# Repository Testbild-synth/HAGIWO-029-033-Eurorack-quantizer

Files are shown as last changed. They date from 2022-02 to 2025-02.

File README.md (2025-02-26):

# HAGIWO 029/033 Eurorack Quantizer Module
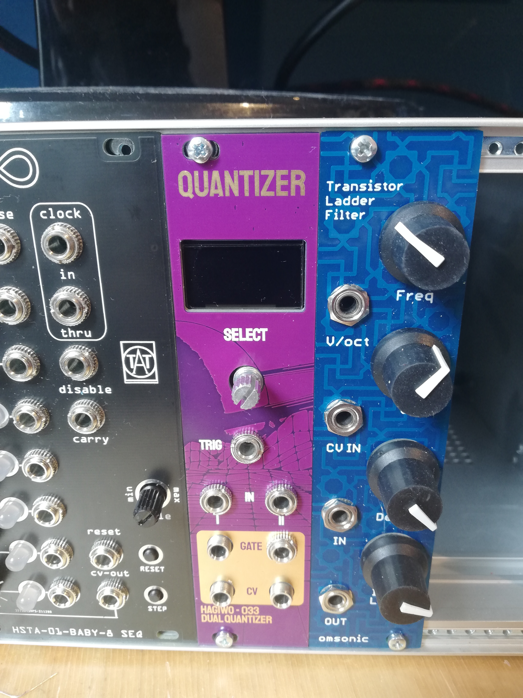
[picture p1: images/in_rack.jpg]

Through hole PCB version of the [HAGIWO 033 dual quantizer](https://www.youtube.com/watch?v=6FJpljEYZq4) and [029 SH101 sequencer](https://www.youtube.com/watch?v=--qb_QYZrTk) Eurorack Module. The modules uses a seeduino xiao and a mcp4725 dac.

The dual quantizer quantizes to notes selectable on the screen and can automatically trigger an envelope on note changes.
The SH101 sequencer allows recording and playback of cv sequences.

## Status
kind of abandoned, this is an old project and I never got around to smoothing out the kinks. Will do a new version sometimes soontm.
I cannot recommend building it at the moment.

## Hardware and PCB
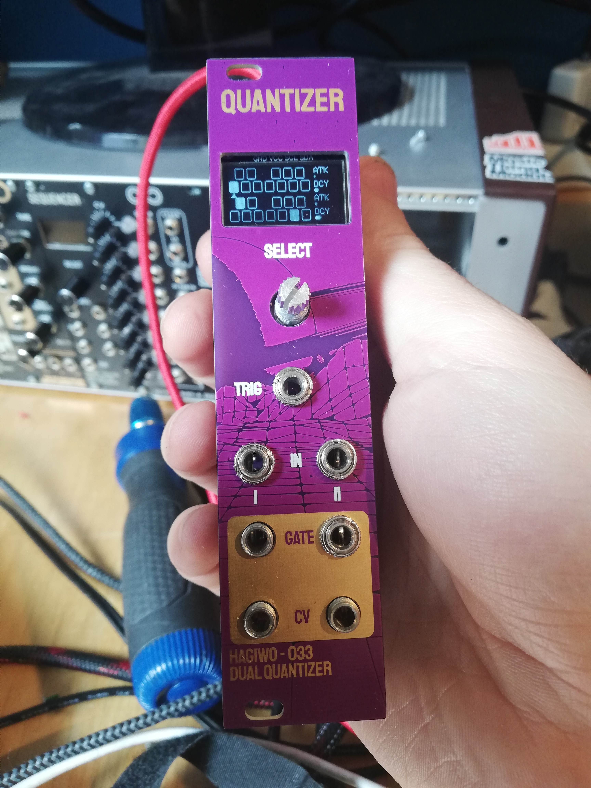
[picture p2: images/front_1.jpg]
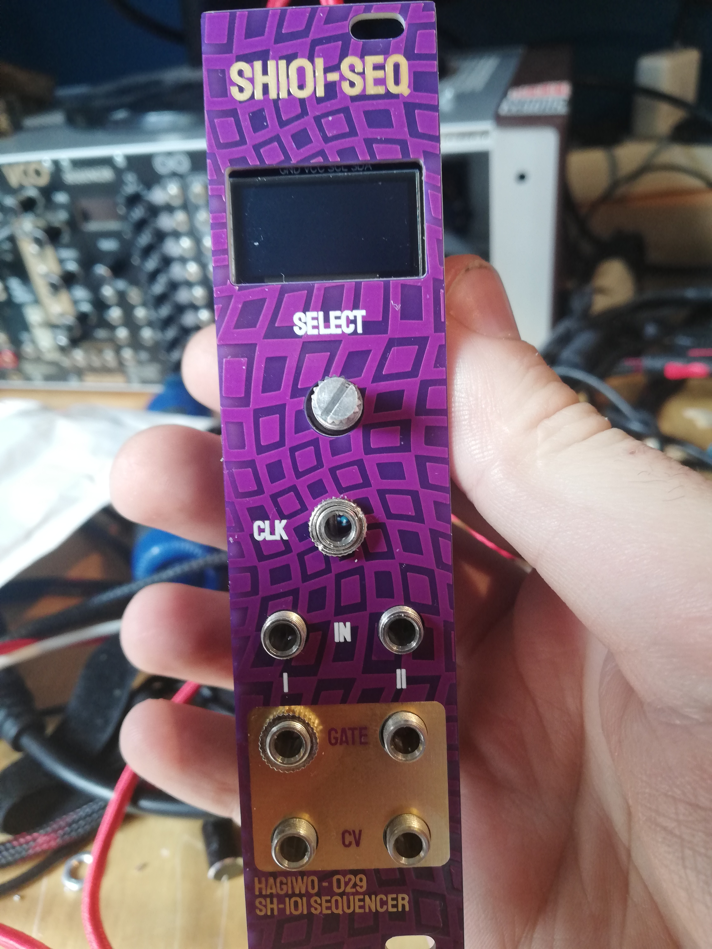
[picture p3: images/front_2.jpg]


You can find the schematic and BOM in the root folder.
For the PCBs, the module has one main circuit PCB, one control circuit PCB and one panel PCB. 
You can order them on any common PCB manufacturing service, I used [JLCPCB](https://jlcpcb.com/).
I made the circuits pcbs under 100mm to get the discount price.
Standard settings should be fine, but as there is exposed copper on the panel you should go with a lead free surface finish (ENIG/Leadfree HASL).
If the panel size is not correctly detected by JLC (happens on some of my exports) manually put 30x128.5 mm.

when ordering the display module, make sure to choose an 0.96 I2C oled module that has the pinout specified as GND-VCC-SCL-SDA as opposed to VCC-GND-SCL-SDA (both exist and the latter will fuck it up).    

Also make sure you order a Seediuno XIAO (with a SAMD21/Cortex M0 chip) as opposed to the XIAO esp32c3 or the XIAO rp2040, those are different chips.

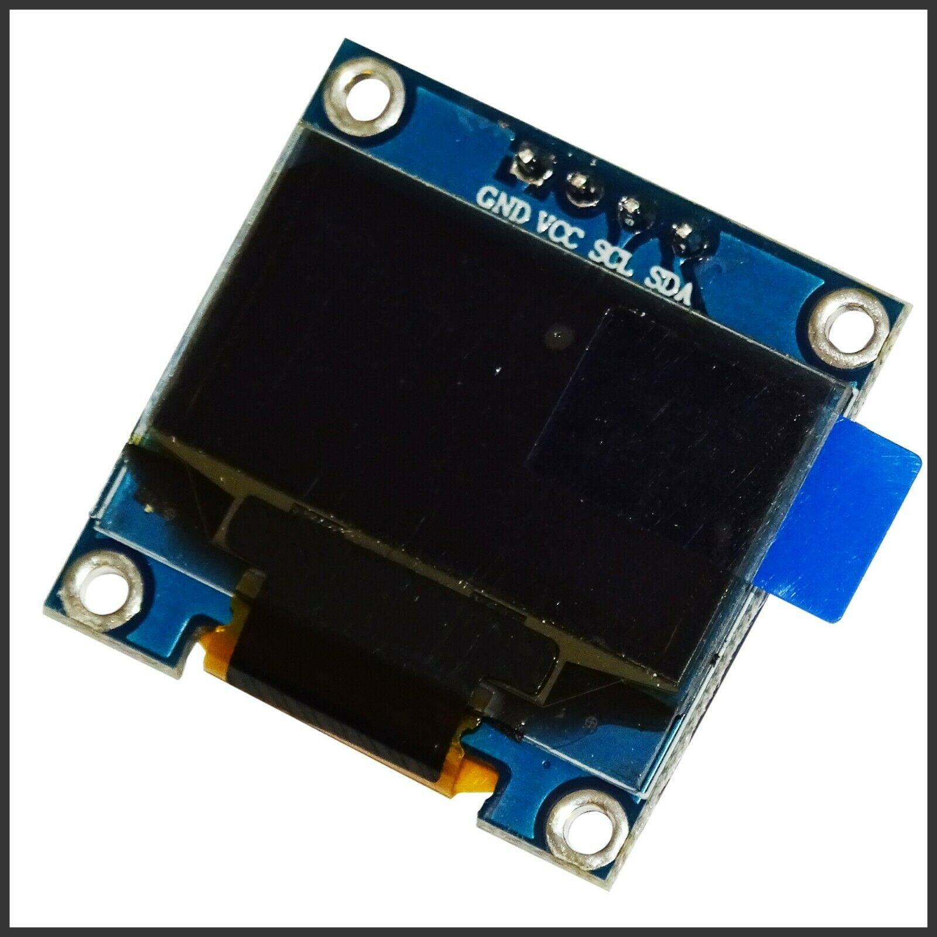
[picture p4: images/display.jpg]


## Assembly

When assembling, you can either use a header for the screen or solder it directly, as it is a litte too tall.
The 7805 voltage regulator is optional, if you do not want to use it, simply solder the SEL header on the back of the main pcb to BOARD instead of REG (meaning you bridge the connection to choose your 5v voltage source to either be 12 regulated to 5v, or a 5V connection of your rack power if you have it).

## Tuning
There are two things  in the circuit that need to be tuned for: The input resistor divider going from 5V to 3.3V, and the output opamp gain to go from 3.3 back to 5V.
I will provide a script to help with this and a detailed description in the future, but for now the short version is: Input resistors are compensated for in code with the ADC_calb parameters. Output gain is adjusted using the trimmers on the main pcb.

## Arduino Code

### Double Quantizer
HAGIWO did great work, but I decided to make some changes to the Arduino code because I had ADC issues on my seeduino Xiao.

The main changes are:
 - HAGIWO had a check that cv is only updated then there's a big enough change from the last value. I took this out since I want to be able to process slow cv changes (i.e. from LFOs), also. 
 - I followed suggestions from [this very nice blog about adc accuracy on samd21](https://blog.thea.codes/getting-the-most-out-of-the-samd21-adc/). With lower input impedance and the changes from this blog, the readings got a lot more accurate on mine. Downside is more latency (in the single ms range) but frankly im willing to take that for more stability/less noise.
 - Also, to make use of this, the note calculation is now done with 12 bit instead of downsampling the adc values to 10 bit.
 - Comment out the specified lines in the code if you dont want the slower adc.

## TODO:
- Test and verify SH101 firmware
- maybe add display indication for played notes

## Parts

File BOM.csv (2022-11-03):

Name | Designator | Footprint | Quantity
18k | R14,R19 | R_AXIAL-0.3 | 2
Header-Male-2.54_1x8 | R9,R3 | TRIMPOT-ELETROCURSOS-FOOTPRINT | 2
33k | R15,R21,R18 | R_AXIAL-0.3 | 3
3k3 | R16,R17 | R_AXIAL-0.3 | 2
1k | R6,R12 | R_AXIAL-0.3 | 2
10k | R7,R1 | R_AXIAL-0.3 | 2
6.8k | R8,R2 | R_AXIAL-0.3 | 2
330 | R10,R11,R4,R5 | R_AXIAL-0.3 | 4
10n ceramic | C7,C8,C9,C10 | RAD-0.1 | 4
470n ceramic | C1,C4 | RAD-0.1 | 2
100n ceramic | C2,C5,C6 | RAD-0.1 | 3
10u electrolytic | C3 | CAP-D4.0×F1.5 | 1
BAT43 | D1,D2,D3,D4,D5,D6 | D_DO-35_SOD27_P7.62MM_HORIZONTAL | 6
Header-Male-2.54_1x8 | H1,H2 | HDR-TH_8P-P2.54-V-M | 2
470 | R13,R20 | R_AXIAL-0.3 | 2
ALPS_ENCODER+PUSHSWITCH | ENC |  | 1
THONKICONN JACK | J1-J7 |  | 7
BC547A | Q1,Q2 | TO92-INLINE | 2
MCP6002-EP | U1 | DIP8 | 1
MCP4725 Breakout | CN1 | MCP4725-B | 1
POWER HEADER | P1 | HDR-IDC-2.54-2X8P | 1
Seeeduino XIAO (SAMD21) | SEEDUINO | SEEDUINO XIAO | 1
7805 Voltage regulator | U3 | 7805 | 1

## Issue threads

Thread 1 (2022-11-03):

Can't compile Arduino Quantizer code due to various errors

guytanium, 2022-11-03:
Hey! I just finished building this module.
I am not sure how to resolve the issues trying to flash my Xiao RP2040. First I was having issues with Encoder interrupts (which I turned off) and now can't seem to pick up anything associated with ADC or PWM.

First I updated all libraries then I installed [arduino-pico](https://github.com/earlephilhower/arduino-pico) into Boards Manager. "Seeed XIAO RP2040" selected in Raspberry Pi RP2040 Boards(2.6.2) under the Boards menu.

Then I manually updated [Encoder](https://github.com/PaulStoffregen/Encoder) to 1.4.3, only 1.4.2 shows in Arduino Library Manager.
I was getting errors that interrupts are not supported such as:
`/Users/guy/Documents/Arduino/libraries/Encoder/utility/interrupt_pins.h:390:2: error: #error "Interrupts are unknown for this board, please add to this code"
  390 | #error "Interrupts are unknown for this board, please add to this code"
      |  ^~~~~
/Users/guy/Documents/Arduino/libraries/Encoder/utility/interrupt_pins.h:393:2: error: #error "Encoder requires interrupt pins, but this board does not have any :("
  393 | #error "Encoder requires interrupt pins, but this board does not have any :("
      |  ^~~~~
/Users/guy/Documents/Arduino/libraries/Encoder/utility/interrupt_pins.h:394:2: error: #error "You could try defining ENCODER_DO_NOT_USE_INTERRUPTS as a kludge."
  394 | #error "You could try defining ENCODER_DO_NOT_USE_INTERRUPTS as a kludge."`

So I switched `#define  ENCODER_OPTIMIZE_INTERRUPTS` to `ENCODER_DO_NOT_USE_INTERRUPTS` to get past this error.

Next set of errors
`WARNING: library FlashStorage claims to run on samd architecture(s) and may be incompatible with your current board which runs on rp2040 architecture(s).
In file included from /Users/guy/Downloads/double_quantizer/double_quantizer.ino:13:
/Users/guy/Documents/Arduino/libraries/Encoder/Encoder.h:68:11: error: 'IO_REG_TYPE' does not name a type; did you mean 'IP_GET_TYPE'?
   68 |  volatile IO_REG_TYPE * pin1_register;
      |           ^~~~~~~~~~~
      |           IP_GET_TYPE
/Users/guy/Documents/Arduino/libraries/Encoder/Encoder.h:69:11: error: 'IO_REG_TYPE' does not name a type; did you mean 'IP_GET_TYPE'?
   69 |  volatile IO_REG_TYPE * pin2_register;
      |           ^~~~~~~~~~~
      |           IP_GET_TYPE
/Users/guy/Documents/Arduino/libraries/Encoder/Encoder.h:70:2: error: 'IO_REG_TYPE' does not name a type; did you mean 'IP_GET_TYPE'?
   70 |  IO_REG_TYPE            pin1_bitmask;
      |  ^~~~~~~~~~~
      |  IP_GET_TYPE
/Users/guy/Documents/Arduino/libraries/Encoder/Encoder.h:71:2: error: 'IO_REG_TYPE' does not name a type; did you mean 'IP_GET_TYPE'?
   71 |  IO_REG_TYPE            pin2_bitmask;
      |  ^~~~~~~~~~~
      |  IP_GET_TYPE
/Users/guy/Documents/Arduino/libraries/Encoder/Encoder.h: In constructor 'Encoder::Encoder(uint8_t, uint8_t)':
/Users/guy/Documents/Arduino/libraries/Encoder/Encoder.h:89:11: error: 'struct Encoder_internal_state_t' has no member named 'pin1_register'
   89 |   encoder.pin1_register = PIN_TO_BASEREG(pin1);
      |           ^~~~~~~~~~~~~
/Users/guy/Documents/Arduino/libraries/Encoder/Encoder.h:89:27: error: 'PIN_TO_BASEREG' was not declared in this scope
   89 |   encoder.pin1_register = PIN_TO_BASEREG(pin1);
      |                           ^~~~~~~~~~~~~~
/Users/guy/Documents/Arduino/libraries/Encoder/Encoder.h:90:11: error: 'struct Encoder_internal_state_t' has no member named 'pin1_bitmask'
   90 |   encoder.pin1_bitmask = PIN_TO_BITMASK(pin1);
      |           ^~~~~~~~~~~~
/Users/guy/Documents/Arduino/libraries/Encoder/Encoder.h:90:26: error: 'PIN_TO_BITMASK' was not declared in this scope
   90 |   encoder.pin1_bitmask = PIN_TO_BITMASK(pin1);
      |                          ^~~~~~~~~~~~~~
/Users/guy/Documents/Arduino/libraries/Encoder/Encoder.h:91:11: error: 'struct Encoder_internal_state_t' has no member named 'pin2_register'
   91 |   encoder.pin2_register = PIN_TO_BASEREG(pin2);
      |           ^~~~~~~~~~~~~
/Users/guy/Documents/Arduino/libraries/Encoder/Encoder.h:92:11: error: 'struct Encoder_internal_state_t' has no member named 'pin2_bitmask'
   92 |   encoder.pin2_bitmask = PIN_TO_BITMASK(pin2);
      |           ^~~~~~~~~~~~
/Users/guy/Documents/Arduino/libraries/Encoder/Encoder.h:99:31: error: 'struct Encoder_internal_state_t' has no member named 'pin1_register'
   99 |   if (DIRECT_PIN_READ(encoder.pin1_register, encoder.pin1_bitmask)) s |= 1;
      |                               ^~~~~~~~~~~~~
/Users/guy/Documents/Arduino/libraries/Encoder/Encoder.h:99:54: error: 'struct Encoder_internal_state_t' has no member named 'pin1_bitmask'
   99 |   if (DIRECT_PIN_READ(encoder.pin1_register, encoder.pin1_bitmask)) s |= 1;
      |                                                      ^~~~~~~~~~~~
/Users/guy/Documents/Arduino/libraries/Encoder/Encoder.h:99:7: error: 'DIRECT_PIN_READ' was not declared in this scope
   99 |   if (DIRECT_PIN_READ(encoder.pin1_register, encoder.pin1_bitmask)) s |= 1;
      |       ^~~~~~~~~~~~~~~
/Users/guy/Documents/Arduino/libraries/Encoder/Encoder.h:100:31: error: 'struct Encoder_internal_state_t' has no member named 'pin2_register'
  100 |   if (DIRECT_PIN_READ(encoder.pin2_register, encoder.pin2_bitmask)) s |= 2;
      |                               ^~~~~~~~~~~~~
/Users/guy/Documents/Arduino/libraries/Encoder/Encoder.h:100:54: error: 'struct Encoder_internal_state_t' has no member named 'pin2_bitmask'
  100 |   if (DIRECT_PIN_READ(encoder.pin2_register, encoder.pin2_bitmask)) s |= 2;
      |                                                      ^~~~~~~~~~~~
/Users/guy/Documents/Arduino/libraries/Encoder/Encoder.h:100:7: error: 'DIRECT_PIN_READ' was not declared in this scope
  100 |   if (DIRECT_PIN_READ(encoder.pin2_register, encoder.pin2_bitmask)) s |= 2;
      |       ^~~~~~~~~~~~~~~
/Users/guy/Documents/Arduino/libraries/Encoder/Encoder.h: In static member function 'static void Encoder::update(Encoder_internal_state_t*)':
/Users/guy/Documents/Arduino/libraries/Encoder/Encoder.h:303:40: error: 'struct Encoder_internal_state_t' has no member named 'pin1_register'
  303 |   uint8_t p1val = DIRECT_PIN_READ(arg->pin1_register, arg->pin1_bitmask);
      |                                        ^~~~~~~~~~~~~
/Users/guy/Documents/Arduino/libraries/Encoder/Encoder.h:303:60: error: 'struct Encoder_internal_state_t' has no member named 'pin1_bitmask'
  303 |   uint8_t p1val = DIRECT_PIN_READ(arg->pin1_register, arg->pin1_bitmask);
      |                                                            ^~~~~~~~~~~~
/Users/guy/Documents/Arduino/libraries/Encoder/Encoder.h:303:19: error: 'DIRECT_PIN_READ' was not declared in this scope
  303 |   uint8_t p1val = DIRECT_PIN_READ(arg->pin1_register, arg->pin1_bitmask);
      |                   ^~~~~~~~~~~~~~~
/Users/guy/Documents/Arduino/libraries/Encoder/Encoder.h:304:40: error: 'struct Encoder_internal_state_t' has no member named 'pin2_register'
  304 |   uint8_t p2val = DIRECT_PIN_READ(arg->pin2_register, arg->pin2_bitmask);
      |                                        ^~~~~~~~~~~~~
/Users/guy/Documents/Arduino/libraries/Encoder/Encoder.h:304:60: error: 'struct Encoder_internal_state_t' has no member named 'pin2_bitmask'
  304 |   uint8_t p2val = DIRECT_PIN_READ(arg->pin2_register, arg->pin2_bitmask);
      |                                                            ^~~~~~~~~~~~
/Users/guy/Downloads/double_quantizer/double_quantizer.ino: In function 'void setup()':
double_quantizer:94:2: error: 'REG_ADC_AVGCTRL' was not declared in this scope
   94 |  REG_ADC_AVGCTRL |= ADC_AVGCTRL_SAMPLENUM_1;
      |  ^~~~~~~~~~~~~~~
double_quantizer:94:21: error: 'ADC_AVGCTRL_SAMPLENUM_1' was not declared in this scope
   94 |  REG_ADC_AVGCTRL |= ADC_AVGCTRL_SAMPLENUM_1;
      |                     ^~~~~~~~~~~~~~~~~~~~~~~
double_quantizer:95:2: error: 'ADC' was not declared in this scope
   95 |  ADC->AVGCTRL.reg = ADC_AVGCTRL_SAMPLENUM_128 | ADC_AVGCTRL_ADJRES(4);
      |  ^~~
double_quantizer:95:21: error: 'ADC_AVGCTRL_SAMPLENUM_128' was not declared in this scope
   95 |  ADC->AVGCTRL.reg = ADC_AVGCTRL_SAMPLENUM_128 | ADC_AVGCTRL_ADJRES(4);
      |                     ^~~~~~~~~~~~~~~~~~~~~~~~~
double_quantizer:95:49: error: 'ADC_AVGCTRL_ADJRES' was not declared in this scope
   95 |  ADC->AVGCTRL.reg = ADC_AVGCTRL_SAMPLENUM_128 | ADC_AVGCTRL_ADJRES(4);
      |                                                 ^~~~~~~~~~~~~~~~~~
/Users/guy/Downloads/double_quantizer/double_quantizer.ino: In function 'void PWM1(int)':
double_quantizer:722:2: error: 'pwm' was not declared in this scope
  722 |  pwm(ENV_OUT_PIN_1, 46000, duty1);
      |  ^~~
/Users/guy/Downloads/double_quantizer/double_quantizer.ino: In function 'void PWM2(int)':
double_quantizer:725:2: error: 'pwm' was not declared in this scope
  725 |  pwm(ENV_OUT_PIN_2, 46000,  duty2);
      |  ^~~
exit status 1
'REG_ADC_AVGCTRL' was not declared in this scope`

Are you using a different set up in board manager? It looks like Arduino IDE doesn't know anything about the pinouts or environment for RP2040. Thanks

Testbild-synth, 2022-11-03:
hi @guytanium , the problem is probably that you are using an RP2040 instead of a regular Xiao, which has a Samd21/cortex m0 chip. Seed studios has kind of confusing naming conventions for the uC boards, but they are two entirely different products. (there is also a xiao esp32 which is yet another different thing altogether)

Hagiwo made the code for the Xiao with the samd21 chip and you will probably have to manually change a bunch of things related to the dac/adc settings if you want to run it on an RP2040 (not even sure if the pins match). I will update the BOM to reflect this more closely in the future

Testbild-synth, 2022-11-03:
if you want to try using the 2040, you can try the following steps:
1. Make sure that the pins actually match (as in that analog/digital io and voltage supply pins for both boards are the same)
2. comment out line 93 and 94 (those are the samd21 related adc settings) and try to compile again
3. Check if adc resolution on the rp2040 is also 12 bit and if you can get the pwm to behave the same way (might be tricky).

But again this is not officially supported, if you get a version working with the 2040 feel free to create a pullrequest and we can add this as a separate firmware

guytanium, 2022-11-03:
Oh wow. That’s embarrassing I bought the wrong microcontroller!  Thanks for the fast reply. I’m sure I can find another use for my 2040, now to source a samd21 chip.

Closed 2022-11-03.

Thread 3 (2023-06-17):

about tuning process

b2unit69, 2023-06-17:
I am currently working on a module, following your project exactly. I do not have any electronic knowledge, so I do not understand the tuning that you explained very well. If you are okay with it, could you please explain the tuning process in detail? Thank you.

Testbild-synth, 2023-07-04:
honestly this was my second ever project and I never really followed through on the explanation. I will try to redo the whole thing soon and make it more usable but for your build ill try to find a solution. I'll get back to you next week

b2unit69, 2023-07-06:
thank you for the answer :)
I did tunning process on my own. Is this correct?

5v to 3.3v (scale down)
Vin(5v) *(R21(33k)/R21(33k)+R19(18k) = Vout(A)
5v:1 - Av:a(AD_CH1_calb) (in my case AD_CH1_calb = 0.971)

3.3v to 5v(scale up)
5v/3.3v = 1.51515
0.51515 = 5k(adjustable)/6.5k
set the 5k trim pot value( in my case around 3.5k)

when cv in volatage around 4.5v to 5v
When a cv in value reaches around 4.5v to 5v, it becomes the same high value. Is this normal?

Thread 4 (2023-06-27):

HAGIWO-029-033-Eurorack-Quantisierer

Terry-Trasher, 2023-06-27:
Hallo,

wie geht es dir?
Ich habe ein Problem Arduino. Ich will die Firmware flashen, aber kommt immer ein Problem mit pwm.

Ich hatte die Firmware von dir genommen.

void PWM1(int duty1) {
  pwm(ENV_OUT_PIN_1, 46000, duty1);
}
void PWM2(int duty2) {
 pwm(ENV_OUT_PIN_2, 46000, duty2);
}

**double_quantizer:721:3: error: 'pwm' was not declared in this scope
   pwm(ENV_OUT_PIN_1, 46000, duty1);
   ^~~**

**double_quantizer:724:2: error: 'pwm' was not declared in this scope
  pwm(ENV_OUT_PIN_2, 46000, duty2);
  ^~~
exit status 1
'pwm' was not declared in this scope**

Wo ist das Problem? Ich hatte in verschiedene Forum belesen, aber bin nicht schlau geworden.

Ich bedanke mich Vorab.

Grüß

Terry

Closed 2023-06-28.

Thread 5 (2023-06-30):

mcp6002 Vss, Vdd wiring in pcb

b2unit69, 2023-06-30:
please check mcp6002 pin4(Vss), pin8(Vdd) connection.
pin4(Vss) is connected 5v and pin8(Vdd) is connected GND in PCB. is this right? let me know..

b2unit69, 2023-07-03:
situation: using 5v from case power supply without 7805
now I can hear sound but don't know well about tunning.

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

Testbild-synth, 2023-07-04:
you are correct. This was an issue with the first batch of pcbs which I thought I fixed years ago but turns out I never really uploaded the files (shame on me).
Sorry you had to go through the build process with a broken pcb and thanks for reminding, I uploaded new files that should reflect the new orientation.

Closed 2023-07-06.

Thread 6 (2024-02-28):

Marking error on control pannel & CV out bug

lookitsgraphic, 2024-02-28:
The marking of 4 resistors on the control panel are wrong, the 2X 18k and 33k resistor are marked as 220k and 330k resistor on the pcb.
So I still have a problem, when I plug in the module, it seems to recognize the CV signals (because it is trig) but the quantizer does not seem to work (the CV signal sent is always the same).

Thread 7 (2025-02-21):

fatal error: FlashAsEEPROM.h: No such file or directory

K-Teck-Dave, 2025-02-21:
i'm a complete arduino novice
what libraries do i need to include?
i installed FlashStorage_SAMD
and AceWire - because Wire.h is missing too...

i'm not sure what to do next

K-Teck-Dave, 2025-02-22:
ok... i have it all working on the screen... but no quantising going on... i'll investigate further

K-Teck-Dave, 2025-02-22:
all sorted... super module... thanks

K-Teck-Dave, 2025-02-22:
closing

Closed 2025-02-22.

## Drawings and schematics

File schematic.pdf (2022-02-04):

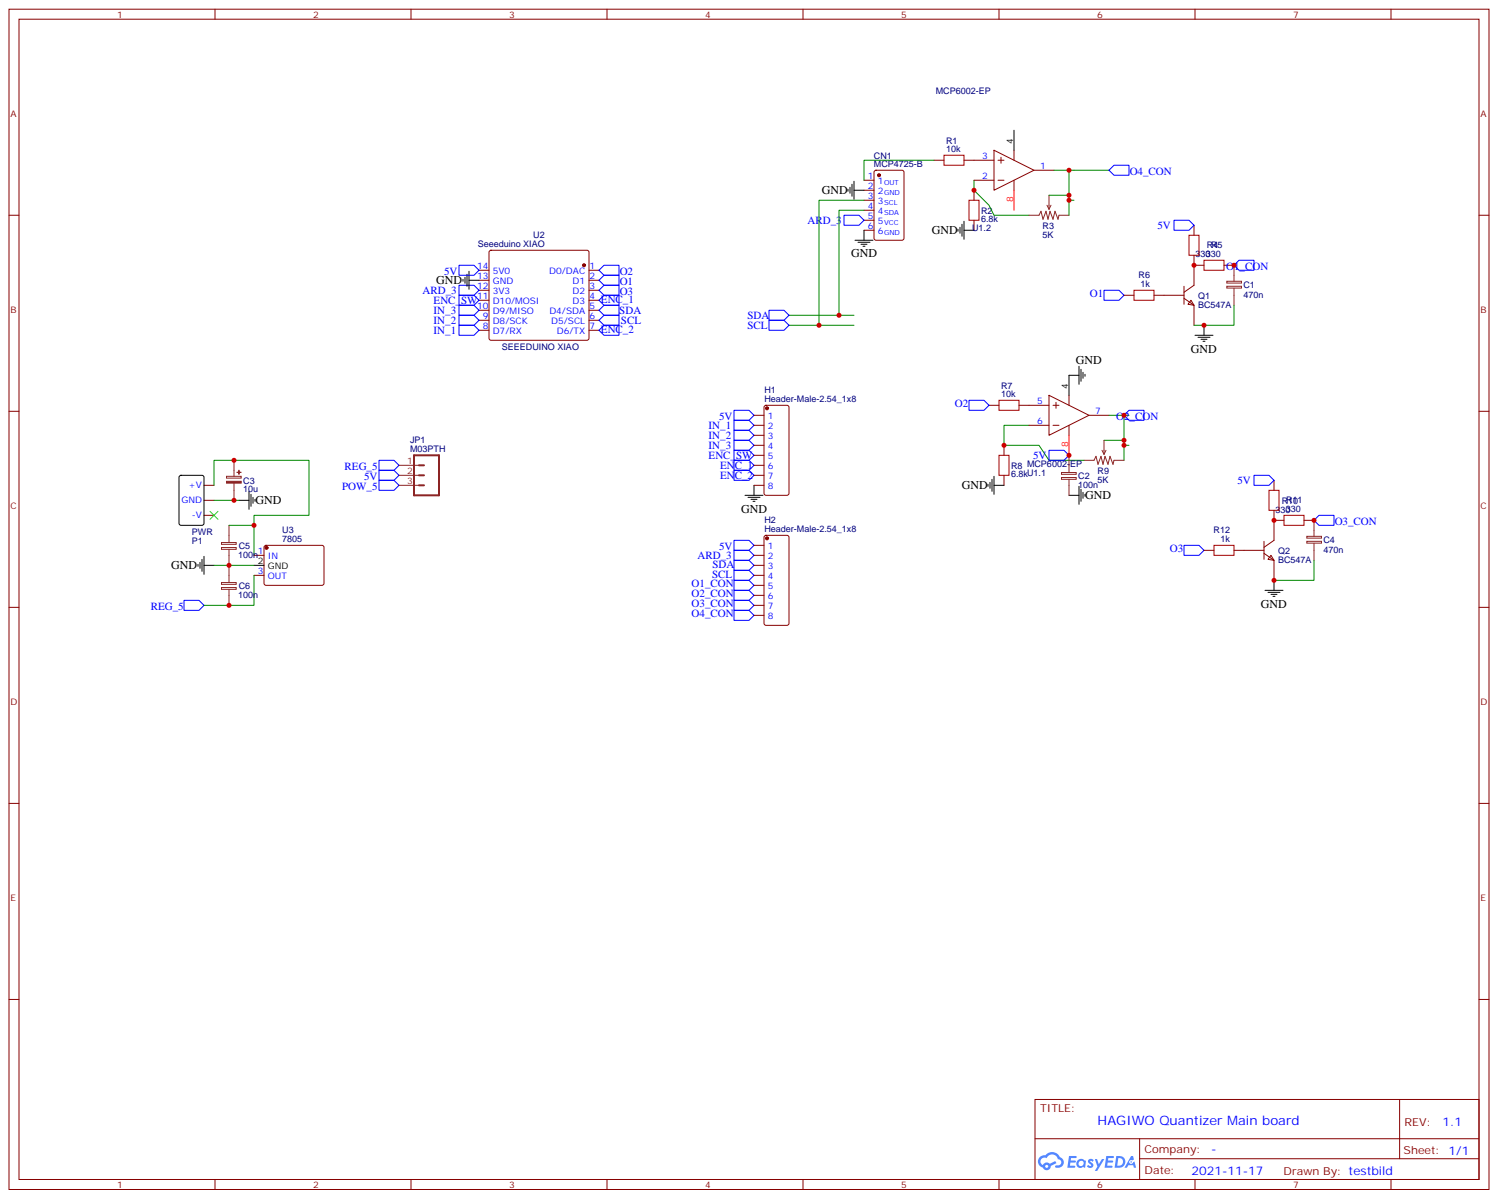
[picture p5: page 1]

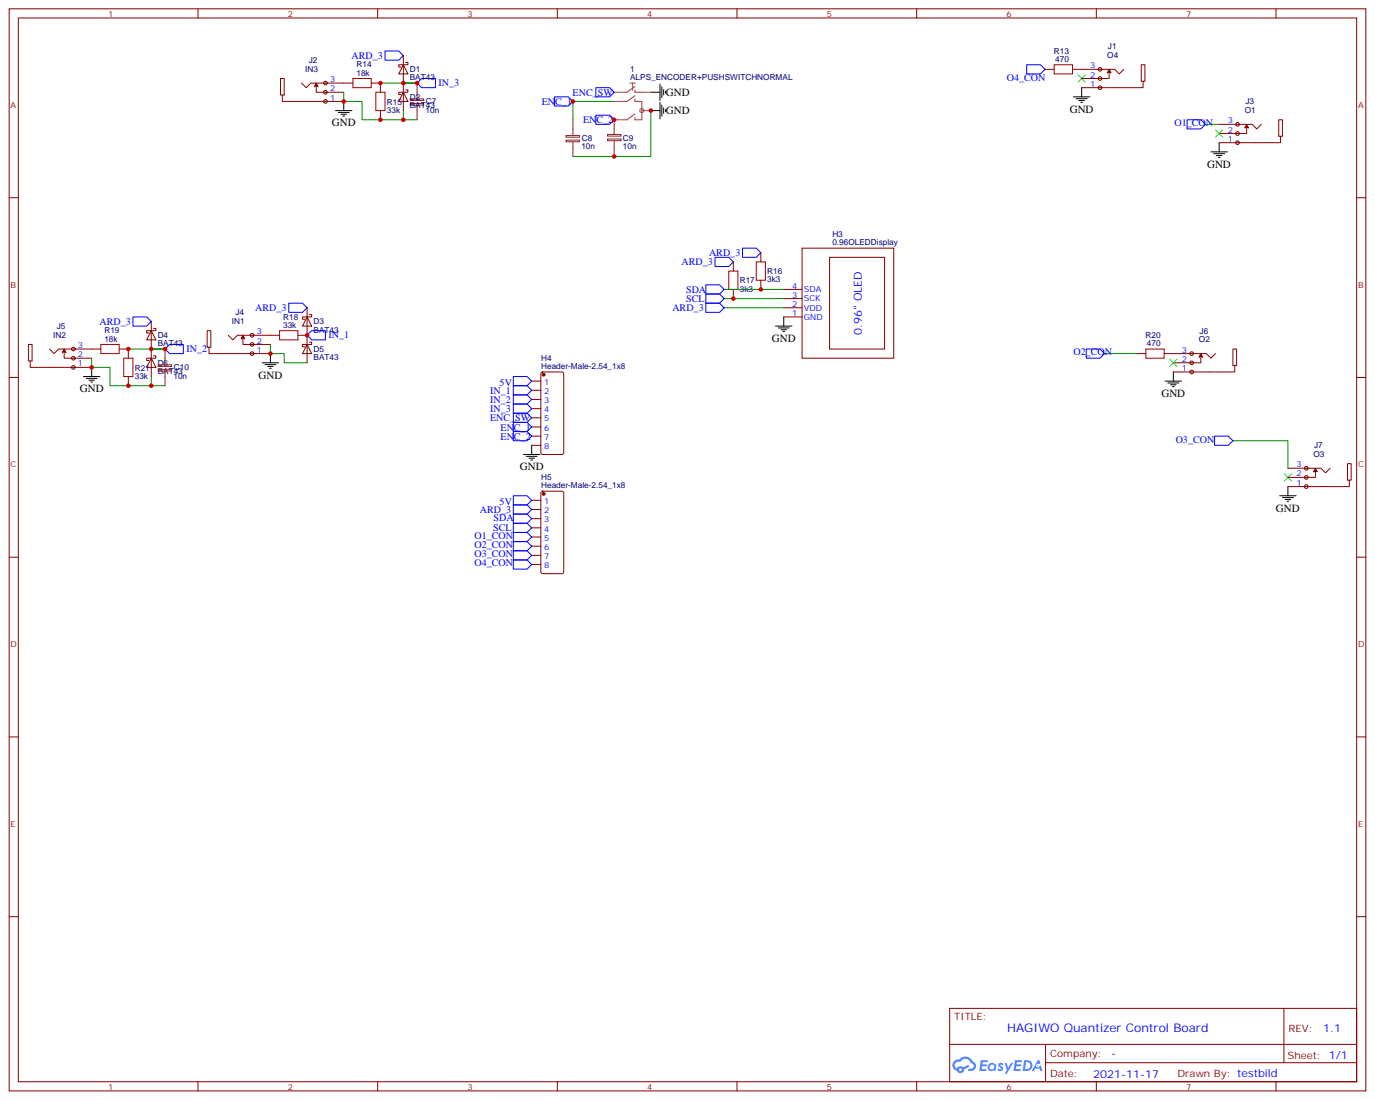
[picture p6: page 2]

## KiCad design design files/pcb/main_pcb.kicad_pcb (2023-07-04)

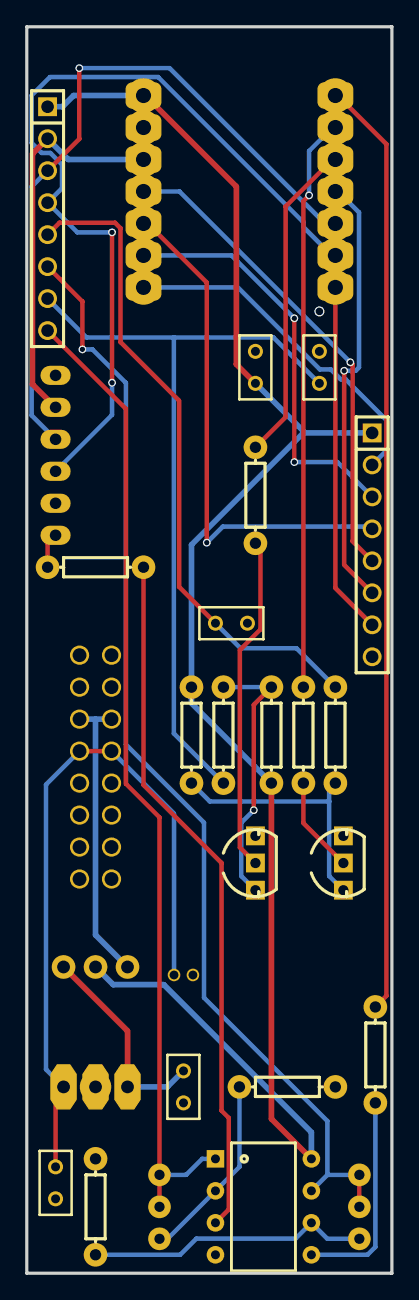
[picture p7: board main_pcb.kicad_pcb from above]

Board: 2 copper layers, 29.0 x 99.0 mm, 28 parts (0 on the bottom side), 30 nets.

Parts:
C1, C4: 470n; RAD-0.1
C2, C5, C6: 100n; RAD-0.1
C3: 10u; CAP-D4.0×F1.5
CN1: MCP4725-B
H4, H5: Header-Male-2.54_1x8; HDR-TH_8P-P2.54-V-M
P1: PWR; HDR-IDC-2.54-2X8P
Q1, Q2: BC547A; TO92-INLINE
R1, R7: 10k; R_AXIAL-0.3
R2, R8: 6.8k; R_AXIAL-0.3
R3, R9: 5K; TRIMPOT-ELETROCURSOS-FOOTPRINT
R4, R5, R10, R11: 330; R_AXIAL-0.3
R6, R12: 1k; R_AXIAL-0.3
SEEDUINO: Seeeduino XIAO; SEEDUINO XIAO
SEL: M03PTH; 1X03
U1: MCP6002-EP; DIP8
U3: 7805

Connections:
5V: C2.2, H4.1, H5.1, R4.2, R10.2, SEEDUINO.14, SEL.2, U1.8
ARD_3: CN1.5, H5.2, SEEDUINO.12
CN1_1: CN1.1, R1.1
ENC_1: H4.6, SEEDUINO.4
ENC_2: H4.7, SEEDUINO.7
ENC_SW: H4.5, SEEDUINO.11
GND: C1.2, C2.1, C3.2, C4.2, C5.1, C6.2, CN1.2, CN1.6, H4.8, P1.3, P1.4, P1.5, P1.6, P1.7, P1.8, Q1.3, Q2.3, R2.1, R8.1, SEEDUINO.13, U1.4, U3.2
IN_1: H4.2, SEEDUINO.8
IN_2: H4.3, SEEDUINO.9
IN_3: H4.4, SEEDUINO.10
O1: R6.1, SEEDUINO.2
O1_CON: C1.1, H5.5, R5.1
O2: R7.1, SEEDUINO.1
O2_CON: H5.6, R9.2, R9.3, U1.7
O3: R12.1, SEEDUINO.3
O3_CON: C4.1, H5.7, R11.1
O4_CON: H5.8, R3.2, R3.3, U1.1
P1_10: C3.1, C5.2, P1.9, P1.10, U3.1
POW_5: P1.11, P1.12, SEL.3
Q1_1: Q1.1, R4.1, R5.2
Q2_1: Q2.1, R10.1, R11.2
R1_2: R1.2, U1.3
R2_2: R2.2, R3.1, U1.2
R6_2: Q1.2, R6.2
R7_2: R7.2, U1.5
R9_1: R8.2, R9.1, U1.6
R12_2: Q2.2, R12.2
REG_5: C6.1, SEL.1, U3.3
SCL: CN1.3, H5.4, SEEDUINO.6
SDA: CN1.4, H5.3, SEEDUINO.5

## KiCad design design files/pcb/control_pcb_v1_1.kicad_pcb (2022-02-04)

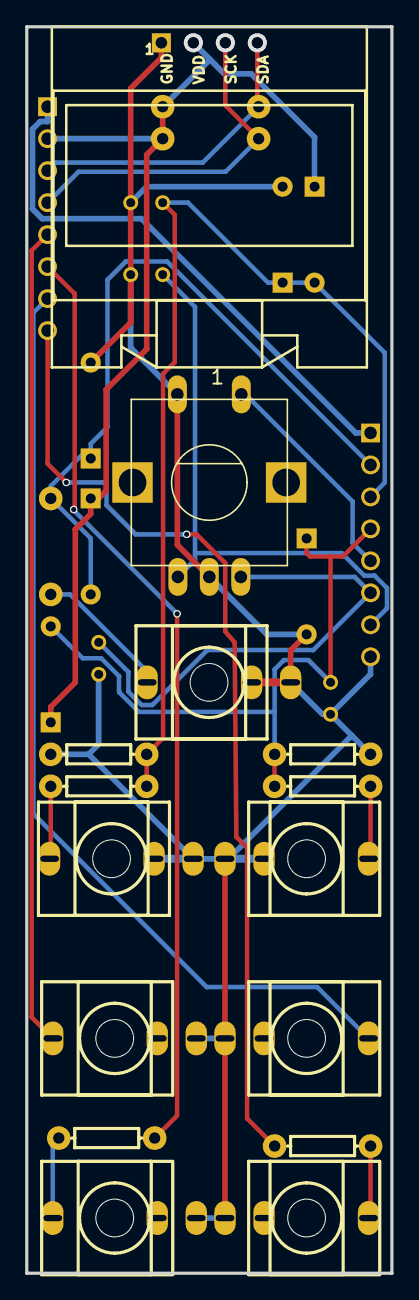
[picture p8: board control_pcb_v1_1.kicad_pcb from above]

Board: 2 copper layers, 29.0 x 99.0 mm, 29 parts (0 on the bottom side), 20 nets.

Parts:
1: ALPS_ENCODER+PUSHSWITCHNORMAL; ENCODER+SWITCH
C7, C8, C9, C10: 10n; RAD-0.1
D1, D2, D3, D4, D5, D6: BAT43; D_DO-35_SOD27_P7.62MM_HORIZONTAL
H1, H2: Header-Male-2.54_1x8; HDR-TH_8P-P2.54-V-M
J1: O4; THONKICONN_1
J2: IN3; THONKICONN_1
J3: O1; THONKICONN_1
J4: IN1; THONKICONN_1
J5: IN2; THONKICONN_1
J6: O2; THONKICONN_1
J7: O3; THONKICONN_1
R13, R20: 470; R_AXIAL-0.3
R14, R19: 18k; R_AXIAL-0.3
R15, R18, R21: 33k; R_AXIAL-0.3
R16, R17: 3k3; R_AXIAL-0.3

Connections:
5V: H1.1, H2.1
ARD_3: D1.1, D3.1, D4.1, H2.2, R16.1, R17.1
ENC_1: 1.B, C8.2, H1.6
ENC_2: 1.A, C9.1, H1.7
ENC_SW: 1.E, H1.5
GND: 1.C, 1.D, C7.1, C8.1, C9.2, C10.1, D2.2, D5.2, D6.2, H1.8, J1.1, J2.1, J2.2, J3.1, J4.1, J4.2, J5.1, J5.2, J6.1, J7.1, R15.2, R21.2
IN_1: D3.2, D5.1, H1.2, R18.1
IN_2: C10.2, D4.2, D6.1, H1.3, R19.1, R21.1
IN_3: C7.2, D1.2, D2.1, H1.4, R14.1, R15.1
J1_3: J1.3, R13.2
J5_3: J5.3, R19.2
J6_3: J6.3, R20.2
O1_CON: H2.5, J3.3
O2_CON: H2.6, R20.1
O3_CON: H2.7, J7.3
O4_CON: H2.8, R13.1
R14_2: J2.3, R14.2
R18_2: J4.3, R18.2
SCL: H2.4, R17.2
SDA: H2.3, R16.2

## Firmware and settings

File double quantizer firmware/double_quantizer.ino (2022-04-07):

#include <FlashAsEEPROM.h>//flash memory use as eeprom
//Display setting
#include <Adafruit_SSD1306.h>
#include <Adafruit_GFX.h>
#define OLED_ADDRESS 0x3C
#define SCREEN_WIDTH 128
#define SCREEN_HEIGHT 64
Adafruit_SSD1306 display(SCREEN_WIDTH, SCREEN_HEIGHT, &Wire, -1);
#include <Wire.h>
//Rotery encoder setting
#define  ENCODER_OPTIMIZE_INTERRUPTS //counter measure of noise
#include <Encoder.h>


#define ENC_PIN_1 3 //rotary encoder left pin
#define ENC_PIN_2 6 //rotary encoder right pin
#define CLK_PIN 7 //Clock input pin
#define CV_1_IN_PIN 8 // channel 1 analog in
#define CV_2_IN_PIN 9 // channel 2 analog in
#define ENC_CLICK_PIN 10 //pin for encoder switch
#define ENV_OUT_PIN_1 1
#define ENV_OUT_PIN_2 2

////////////////////////////////////////////
// ADC calibration. Change these according to your resistor values to make readings more accurate
float AD_CH1_calb = 0.98;//reduce resistance error
float AD_CH2_calb = 0.98;//reduce resistance error
/////////////////////////////////////////


Encoder myEnc(ENC_PIN_1, ENC_PIN_2);//rotery encoder library setting
float oldPosition  = -999;//rotery encoder library setting
float newPosition = -999;//rotery encoder library setting
int i = 1;

bool SW = 0;
bool old_SW = 0;
bool CLK_in = 0;
bool old_CLK_in = 0;
byte mode = 0; //0=select,1=atk1,2=dcy1,3=atk2,4=dcy2

float AD_CH1, old_AD_CH1, AD_CH2, old_AD_CH2;


int CV_in1, CV_in2;
float CV_out1, CV_out2, old_CV_out1, old_CV_out2;
long gate_timer1, gate_timer2; //EG curve progress speed

int cmp1, cmp2; //Detect closest note
int k = 0;

//envelope curve setting
int ad[200] = {//envelope table
 0, 15, 30, 44, 59, 73, 87, 101,  116,  130,  143,  157,  170,  183,  195,  208,  220,  233,  245,  257,  267,  279,  290,  302,  313,  324,  335,  346,  355,  366,  376,  386,  397,  405,  415,  425,  434,  443,  452,  462,  470,  479,  488,  495,  504,  513,  520,  528,  536,  544,  552,  559,  567,  573,  581,  589,  595,  602,  609,  616,  622,  629,  635,  642,  648,  654,  660,  666,  672,  677,  683,  689,  695,  700,  706,  711,  717,  722,  726,  732,  736,  741,  746,  751,  756,  760,  765,  770,  774,  778,  783,  787,  791,  796,  799,  803,  808,  811,  815,  818,  823,  826,  830,  834,  837,  840,  845,  848,  851,  854,  858,  861,  864,  866,  869,  873,  876,  879,  881,  885,  887,  890,  893,  896,  898,  901,  903,  906,  909,  911,  913,  916,  918,  920,  923,  925,  927,  929,  931,  933,  936,  938,  940,  942,  944,  946,  948,  950,  952,  954,  955,  957,  960,  961,  963,  965,  966,  968,  969,  971,  973,  975,  976,  977,  979,  980,  981,  983,  984,  986,  988,  989,  990,  991,  993,  994,  995,  996,  997,  999,  1000, 1002, 1003, 1004, 1005, 1006, 1007, 1008, 1009, 1010, 1012, 1013, 1014, 1014, 1015, 1016, 1017, 1018, 1019, 1020
};
int ad1 = 0;//PWM DUTY reference
int ad2 = 0;//PWM DUTY reference
bool ad_trg1 = 0;
bool ad_trg2 = 0;
int atk1, atk2, dcy1, dcy2; //attack time,decay time
bool sync1, sync2; //0=sync with trig , 1=sync with note change
int sensitivity_ch1, sensitivity_ch2, oct1, oct2; //sens = AD input attn,amp.oct=octave shift

//CV setting
int cv_qnt_thr_buf1[62];//input quantize
int cv_qnt_thr_buf2[62];//input quantize
byte search_qnt = 0;
bool note1[12];//1=note valid,0=note invalid
bool note2[12];
byte note_str1, note_str11, note_str2, note_str22;

//display
bool disp_reflesh = 1;//0=not reflesh display , 1= reflesh display , countermeasure of display reflesh bussy

//-------------------------------Initial setting--------------------------
void setup() {
 analogWriteResolution(10);
 analogReadResolution(12);
 pinMode(CLK_PIN, INPUT_PULLDOWN); //CLK in
 pinMode(CV_1_IN_PIN, INPUT);//IN1
 pinMode(CV_2_IN_PIN, INPUT);//IN2
 pinMode(ENC_CLICK_PIN, INPUT_PULLUP);//push sw
 pinMode(ENV_OUT_PIN_1, OUTPUT); //CH1 EG out
 pinMode(ENV_OUT_PIN_2, OUTPUT); //CH2 EG out
 // OLED initialize
 display.begin(SSD1306_SWITCHCAPVCC, 0x3C);
 display.clearDisplay();

 //I2C connect
 Wire.begin();

 // ADC settings. These increase ADC reading stability but at the cost of cycle time. Takes around 0.7ms for one reading with these
 REG_ADC_AVGCTRL |= ADC_AVGCTRL_SAMPLENUM_1;
 ADC->AVGCTRL.reg = ADC_AVGCTRL_SAMPLENUM_128 | ADC_AVGCTRL_ADJRES(4);


 //read stored data
 if (EEPROM.isValid() == 1) { //already writed eeprom
   note_str1 = EEPROM.read(1);
   note_str11 = EEPROM.read(2);
   note_str2 = EEPROM.read(3);
   note_str22 = EEPROM.read(4);
   atk1 = EEPROM.read(5);
   dcy1 = EEPROM.read(6);
   atk2 = EEPROM.read(7);
   dcy2 = EEPROM.read(8);
   sync1 = EEPROM.read(9);
   sync2 = EEPROM.read(10);
   oct1 = EEPROM.read(11);
   oct2 = EEPROM.read(12);
   sensitivity_ch1 = EEPROM.read(13);
   sensitivity_ch2 = EEPROM.read(14);
 }
 else if ( EEPROM.isValid() == 0) { //no eeprom data , setting any number to eeprom
   note_str1 = 0;
   note_str11 = 0;
   note_str2 = 2;
   note_str22 = 2;
   atk1 = 1;
   dcy1 = 4;
   atk2 = 2;
   dcy2 = 6;
   sync1 = 1;
   sync2 = 1;
   oct1 = 2;
   oct2 = 2;
   sensitivity_ch1 = 4;
   sensitivity_ch2 = 4;
 }
 //setting stored note data
 for ( int j = 0; j <= 7 ; j++ ) {
   note1[j] = bitRead(note_str1, j);
   note2[j] = bitRead(note_str2, j);
 }
 for ( int j = 0; j <= 3 ; j++ ) {
   note1[j + 8] = bitRead(note_str11, j);
   note2[j + 8] = bitRead(note_str22, j);
 }

 //initial quantizer setting
 k = 0;
 for (byte j = 0; j <= 62; j++) {
   if (note1[j % 12] == 1) {
     cv_qnt_thr_buf1[k] = 17 * j - 8;
     k++;
   }
 }
 k = 0;
 for (byte j = 0; j <= 62; j++) {
   if (note2[j % 12] == 1) {
     cv_qnt_thr_buf2[k] = 17 * j - 8;
     k++;
   }
 }
}

void loop() {
 old_SW = SW;
 old_CLK_in = CLK_in;
 old_CV_out1 = CV_out1;
 old_CV_out2 = CV_out2;
 old_AD_CH1 = AD_CH1;
 old_AD_CH2 = AD_CH2;

 //-------------------------------Rotery endoder--------------------------
 newPosition = myEnc.read();
 if ( (newPosition - 3) / 4  > oldPosition / 4) { //4 is resolution of encoder
   oldPosition = newPosition;
   disp_reflesh = 1;
   switch (mode) {
     case 0:
       i = i - 1;
       if (i < 0) {
         i = 34;
       }
       break;
     case 1:
       atk1--;
       break;
     case 2:
       dcy1--;
       break;
     case 3:
       atk2--;
       break;
     case 4:
       dcy2--;
       break;
   }
 }
 else if ( (newPosition + 3) / 4  < oldPosition / 4 ) { //4 is resolution of encoder
   oldPosition = newPosition;
   disp_reflesh = 1;
   switch (mode) {
     case 0:
       i = i + 1;
       if (34 < i) {
         i = 0;
       }
       break;
     case 1:
       atk1++;
       break;
     case 2:
       dcy1++;
       break;
     case 3:
       atk2++;
       break;
     case 4:
       dcy2++;
       break;
   }
 }
 i = constrain(i, 0, 34);
 atk1 = constrain(atk1, 1, 26);
 dcy1 = constrain(dcy1, 1, 26);
 atk2 = constrain(atk2, 1, 26);
 atk2 = constrain(atk2, 1, 26);
 dcy2 = constrain(dcy2, 1, 26);

 //-----------------PUSH SW------------------------------------
 SW = digitalRead(ENC_CLICK_PIN);
 if (SW == 1 && old_SW != 1) {
   disp_reflesh = 1;
   if (i <= 11 && i >= 0 && mode == 0) {
     note1[i] = !note1[i];
   }
   else if (i >= 14 && i <= 25 && mode == 0) {
     note2[i - 14] = !note2[i - 14];
   }
   else if (i == 12 && mode == 0) { //CH1 atk setting
     mode = 1;//atk1 setting
   }
   else if (i == 12 && mode == 1) { //CH1 atk setting
     mode = 0;
   }
   else if (i == 13 && mode == 0) { //CH1 atk setting
     mode = 2;//dcy1 setting
   }
   else if (i == 13 && mode == 2) { //CH1 atk setting
     mode = 0;
   }
   else if (i == 26 && mode == 0) { //CH1 atk setting
     mode = 3;//atk2 setting
   }
   else if (i == 26 && mode == 3) { //CH1 atk setting
     mode = 0;
   }
   else if (i == 27 && mode == 0) { //CH1 atk setting
     mode = 4;//dcy2 setting
   }
   else if (i == 27 && mode == 4) { //CH1 atk setting
     mode = 0;
   }
   else if (i == 28) { //CH1 sync setting
     sync1 = !sync1;
   }
   else if (i == 29) { //CH2 sync setting
     sync2 = !sync2;
   }
   else if (i == 30) { //CH1 oct setting
     oct1++;
     if (oct1 > 4) {
       oct1 = 0;
     }
   }
   else if (i == 31) { //CH2 oct setting
     oct2++;
     if (oct2 > 4) {
       oct2 = 0;
     }
   }
   else if (i == 32) { //CH1 sens setting
     sensitivity_ch1++;
     if (sensitivity_ch1 > 8) {
       sensitivity_ch1 = 0;
     }
   }
   else if (i == 33) { //CH2 sens setting
     sensitivity_ch2++;
     if (sensitivity_ch2 > 8) {
       sensitivity_ch2 = 0;
     }
   }
   else if (i == 34) { //CH1 sync setting
     save();
   }

   //select note set
   k = 0;
   for (byte j = 0; j <= 62; j++) {
     if (note1[j % 12] == 1) {
       cv_qnt_thr_buf1[k] = 17 * j - 8;
       k++;
     }
   }
   k = 0;
   for (byte j = 0; j <= 62; j++) {
     if (note2[j % 12] == 1) {
       cv_qnt_thr_buf2[k] = 17 * j - 8;
       k++;
     }
   }
 }

 //-------------------------------Analog read and qnt setting--------------------------
 AD_CH1 = analogRead(CV_1_IN_PIN) / AD_CH1_calb; 
 AD_CH1 = AD_CH1 * (16 + sensitivity_ch1) / 20; //sens setting
  if(AD_CH1 > 4095){
   AD_CH1 = 4095;
 }
  for ( search_qnt = 0; search_qnt <= 61 ; search_qnt++ ) {// quantize
     if ( AD_CH1 >= cv_qnt_thr_buf1[search_qnt]*4 && AD_CH1 < cv_qnt_thr_buf1[search_qnt + 1]*4) {
       cmp1 = AD_CH1 - cv_qnt_thr_buf1[search_qnt]*4;//Detect closest note
       cmp2 = cv_qnt_thr_buf1[search_qnt + 1]*4 - AD_CH1;//Detect closest note
       break;
     }
   }
   if (cmp1 >= cmp2) {//Detect closest note
     CV_out1 = (cv_qnt_thr_buf1[search_qnt + 1] + 8) / 17 * 68.25 + (oct1 - 2) * 12 * 68.25;
     CV_out1 = constrain(CV_out1, 0, 4095);
   }
   else if (cmp2 > cmp1) {//Detect closest note
     CV_out1 = (cv_qnt_thr_buf1[search_qnt] + 8) / 17 * 68.25 + (oct1 - 2) * 12 * 68.25;
     CV_out1 = constrain(CV_out1, 0, 4095);
   }
 AD_CH2 = analogRead(CV_2_IN_PIN) / AD_CH2_calb; //12bit to 10bit
 AD_CH2 = AD_CH2 * (16 + sensitivity_ch2) / 20; //sens setting
  if(AD_CH2 > 4095){
   AD_CH2 = 4095;
 }
   for ( search_qnt = 0; search_qnt <= 61 ; search_qnt++ ) {// quantize
     if ( AD_CH2 >= cv_qnt_thr_buf2[search_qnt]*4 && AD_CH2 < cv_qnt_thr_buf2[search_qnt + 1]*4) {
       cmp1 = AD_CH2 - cv_qnt_thr_buf1[search_qnt]*4;
       cmp2 = cv_qnt_thr_buf1[search_qnt + 1]*4 - AD_CH2;
       break;
     }
   }
   if (cmp1 >= cmp2) {
     CV_out2 = (cv_qnt_thr_buf2[search_qnt + 1] + 8) / 17 * 68.25 + (oct2 - 2) * 12 * 68.25;
     CV_out2 = constrain(CV_out2, 0, 4095);
   }
   else if (cmp2 > cmp1) {
     CV_out2 = (cv_qnt_thr_buf2[search_qnt] + 8) / 17 * 68.25 + (oct2 - 2) * 12 * 68.25;
     CV_out2 = constrain(CV_out2, 0, 4095);
   }
 
 //-------------------------------OUTPUT SETTING--------------------------
 CLK_in = digitalRead(CLK_PIN);

 //trig sync trigger detect
 if (CLK_in == 1 && old_CLK_in == 0) {
   if (sync1 == 0) {
     ad1 = 0;
     ad_trg1 = 1;
     gate_timer1 = micros();
     if (atk1 == 1) {
       ad1 = 200; //no attack time
     }
   }
   if (sync2 == 0)
     ad2 = 0;
   ad_trg2 = 1;
   gate_timer2 = micros();
   if (atk2 == 1) {
     ad2 = 200; //no attack time
   }
 }

 //note sync trigger detect
 if (sync1 == 1 && old_CV_out1 != CV_out1) {
   ad1 = 0;
   ad_trg1 = 1;
   gate_timer1 = micros();
   if (atk1 == 1) {
     ad1 = 200; //no attack time
   }
 }
 if (sync2 == 1 && old_CV_out2 != CV_out2) {
   ad2 = 0;
   ad_trg2 = 1;
   gate_timer2 = micros();
   if (atk2 == 1) {
     ad2 = 200; //no attack time
   }
 }

 //envelope ch1 out
 if ( gate_timer1 + (atk1 - 1) * 200 <= micros() && ad_trg1 == 1 && ad1 <= 199) {
   ad1++;
   gate_timer1 = micros();
 }
 else if ( gate_timer1 + (dcy1 - 1) * 600 <= micros() && ad_trg1 == 1 && ad1 > 199) {
   ad1++;
   gate_timer1 = micros();
 }

 if (ad1 <= 199) {
   PWM1(1021 - ad[ad1]);
 }
 else if (ad1 > 199 && ad1 < 399) {
   PWM1(ad[ad1 - 200]);
 }
 else  if (ad1 >= 399) {
   PWM1(1023);
   ad_trg1 = 0;
 }

 //envelope ch2 out
 if ( gate_timer2 + (atk2 - 1) * 200 <= micros() && ad_trg2 == 1 && ad2 <= 199) {
   ad2++;
   gate_timer2 = micros();
 }
 else if ( gate_timer2 + (dcy2 - 1) * 600 <= micros() && ad_trg2 == 1 && ad2 > 199) {
   ad2++;
   gate_timer2 = micros();
 }

 if (ad2 <= 199) {
   PWM2(1021 - ad[ad2]);
 }
 else if (ad2 > 199 && ad2 < 399) {
   PWM2(ad[ad2 - 200]);
 }
 else  if (ad2 >= 399) {
   PWM2(1023);
   ad_trg2 = 0;
 }

 //DAC OUT
 if (old_CV_out1 != CV_out1) {
   intDAC(CV_out1);
 }
 if (old_CV_out2 != CV_out2) {
   MCP(CV_out2);
 }

 //display out
 if (disp_reflesh == 1) {
   OLED_display();//reflesh display
   disp_reflesh = 0;
 }
}


//-----------------------------DISPLAY----------------------------------------
void OLED_display() {
 display.clearDisplay();
 display.setTextSize(1);
 display.setTextColor(WHITE);

 if (i <= 27) {
   if (note1[1] == 0) {
     display.drawRoundRect(7, 0, 11, 13, 2, WHITE);
   }
   else if (note1[1] == 1) {
     display.fillRoundRect(7, 0, 11, 13, 2, WHITE);
   }

   if (note1[3] == 0) {
     display.drawRoundRect(7 + 14 * 1, 0, 11, 13, 2, WHITE);
   }
   else if (note1[3] == 1) {
     display.fillRoundRect(7 + 14 * 1, 0, 11, 13, 2, WHITE);
   }

   if (note1[6] == 0) {
     display.drawRoundRect(8 + 14 * 3, 0, 11, 13, 2, WHITE);
   }
   else if (note1[6] == 1) {
     display.fillRoundRect(8 + 14 * 3, 0, 11, 13, 2, WHITE);
   }
   if (note1[8] == 0) {
     display.drawRoundRect(8 + 14 * 4, 0, 11, 13, 2, WHITE);
   }
   else if (note1[8] == 1) {
     display.fillRoundRect(8 + 14 * 4, 0, 11, 13, 2, WHITE);
   }
   if (note1[10] == 0) {
     display.drawRoundRect(8 + 14 * 5, 0, 11, 13, 2, WHITE);
   }
   else if (note1[10] == 1) {
     display.fillRoundRect(8 + 14 * 5, 0, 11, 13, 2, WHITE);
   }
   if (note1[0] == 0) {
     display.drawRoundRect(0, 15, 11, 13, 2, WHITE);
   }
   else if (note1[0] == 1) {
     display.fillRoundRect(0, 15, 11, 13, 2, WHITE);
   }
   if (note1[2] == 0) {
     display.drawRoundRect(0 + 14 * 1, 15, 11, 13, 2, WHITE);
   }
   else if (note1[2] == 1) {
     display.fillRoundRect(0 + 14 * 1, 15, 11, 13, 2, WHITE);
   }
   if (note1[4] == 0) {
     display.drawRoundRect(0 + 14 * 2, 15, 11, 13, 2, WHITE);
   }
   else if (note1[4] == 1) {
     display.fillRoundRect(0 + 14 * 2, 15, 11, 13, 2, WHITE);
   }
   if (note1[5] == 0) {
     display.drawRoundRect(0 + 14 * 3, 15, 11, 13, 2, WHITE);
   }
   else if (note1[5] == 1) {
     display.fillRoundRect(0 + 14 * 3, 15, 11, 13, 2, WHITE);
   }
   if (note1[7] == 0) {
     display.drawRoundRect(0 + 14 * 4, 15, 11, 13, 2, WHITE);
   }
   else if (note1[7] == 1) {
     display.fillRoundRect(0 + 14 * 4, 15, 11, 13, 2, WHITE);
   }
   if (note1[9] == 0) {
     display.drawRoundRect(0 + 14 * 5, 15, 11, 13, 2, WHITE);
   }
   else if (note1[9] == 1) {
     display.fillRoundRect(0 + 14 * 5, 15, 11, 13, 2, WHITE);
   }
   if (note1[11] == 0) {
     display.drawRoundRect(0 + 14 * 6, 15, 11, 13, 2, WHITE);
   }
   else if (note1[11] == 1) {
     display.fillRoundRect(0 + 14 * 6, 15, 11, 13, 2, WHITE);
   }


   if (note2[1] == 0) {
     display.drawRoundRect(7, 0 + 34, 11, 13, 2, WHITE);
   }
   else if (note2[1] == 1) {
     display.fillRoundRect(7, 0 + 34, 11, 13, 2, WHITE);
   }

   if (note2[3] == 0) {
     display.drawRoundRect(7 + 14 * 1, 0 + 34, 11, 13, 2, WHITE);
   }
   else if (note2[3] == 1) {
     display.fillRoundRect(7 + 14 * 1, 0 + 34, 11, 13, 2, WHITE);
   }

   if (note2[6] == 0) {
     display.drawRoundRect(8 + 14 * 3, 0 + 34, 11, 13, 2, WHITE);
   }
   else if (note2[6] == 1) {
     display.fillRoundRect(8 + 14 * 3, 0 + 34, 11, 13, 2, WHITE);
   }
   if (note2[8] == 0) {
     display.drawRoundRect(8 + 14 * 4, 0 + 34, 11, 13, 2, WHITE);
   }
   else if (note2[8] == 1) {
     display.fillRoundRect(8 + 14 * 4, 0 + 34, 11, 13, 2, WHITE);
   }
   if (note2[10] == 0) {
     display.drawRoundRect(8 + 14 * 5, 0 + 34, 11, 13, 2, WHITE);
   }
   else if (note2[10] == 1) {
     display.fillRoundRect(8 + 14 * 5, 0 + 34, 11, 13, 2, WHITE);
   }
   if (note2[0] == 0) {
     display.drawRoundRect(0, 15 + 34, 11, 13, 2, WHITE);
   }
   else if (note2[0] == 1) {
     display.fillRoundRect(0, 15 + 34, 11, 13, 2, WHITE);
   }
   if (note2[2] == 0) {
     display.drawRoundRect(0 + 14 * 1, 15 + 34, 11, 13, 2, WHITE);
   }
   else if (note2[2] == 1) {
     display.fillRoundRect(0 + 14 * 1, 15 + 34, 11, 13, 2, WHITE);
   }
   if (note2[4] == 0) {
     display.drawRoundRect(0 + 14 * 2, 15 + 34, 11, 13, 2, WHITE);
   }
   else if (note2[4] == 1) {
     display.fillRoundRect(0 + 14 * 2, 15 + 34, 11, 13, 2, WHITE);
   }
   if (note2[5] == 0) {
     display.drawRoundRect(0 + 14 * 3, 15 + 34, 11, 13, 2, WHITE);
   }
   else if (note2[5] == 1) {
     display.fillRoundRect(0 + 14 * 3, 15 + 34, 11, 13, 2, WHITE);
   }
   if (note2[7] == 0) {
     display.drawRoundRect(0 + 14 * 4, 15 + 34, 11, 13, 2, WHITE);
   }
   else if (note2[7] == 1) {
     display.fillRoundRect(0 + 14 * 4, 15 + 34, 11, 13, 2, WHITE);
   }
   if (note2[9] == 0) {
     display.drawRoundRect(0 + 14 * 5, 15 + 34, 11, 13, 2, WHITE);
   }
   else if (note2[9] == 1) {
     display.fillRoundRect(0 + 14 * 5, 15 + 34, 11, 13, 2, WHITE);
   }
   if (note2[11] == 0) {
     display.drawRoundRect(0 + 14 * 6, 15 + 34, 11, 13, 2, WHITE);
   }
   else if (note2[11] == 1) {
     display.fillRoundRect(0 + 14 * 6, 15 + 34, 11, 13, 2, WHITE);
   }


   //draw triangle
   if (i <= 4) {
     display.fillTriangle(5 + i * 7, 28, 2 + i * 7, 33, 8 + i * 7, 33, WHITE);
   }
   else if (i >= 5 && i <= 11) {
     display.fillTriangle(12 + i * 7, 28, 9 + i * 7, 33, 15 + i * 7, 33, WHITE);
   }
   else if (i == 12 && mode == 0) {
     display.drawTriangle(127, 0, 127, 6, 121, 3, WHITE);
   }
   else if (i == 12 && mode == 1) {
     display.fillTriangle(127, 0, 127, 6, 121, 3, WHITE);
   }
   else if (i == 13 && mode == 0) {
     display.drawTriangle(127, 16, 127, 22, 121, 19, WHITE);
   }
   else if (i == 13 && mode == 2) {
     display.fillTriangle(127, 16, 127, 22, 121, 19, WHITE);
   }
   else if (i >= 14 && i <= 18) {
     display.fillTriangle(12 + (i - 15) * 7, 33, 9 + (i - 15) * 7, 28, 15 + (i - 15) * 7, 28, WHITE);
   }
   else if (i >= 19 && i <= 25) {
     display.fillTriangle(12 + (i - 14) * 7, 33, 9 + (i - 14) * 7, 28, 15 + (i - 14) * 7, 28, WHITE);
   }
   else if (i == 26 && mode == 0) {
     display.drawTriangle(127, 32, 127, 38, 121, 35, WHITE);
   }
   else if (i == 26 && mode == 3) {
     display.fillTriangle(127, 32, 127, 38, 121, 35, WHITE);
   }
   else if (i == 27 && mode == 0) {
     display.drawTriangle(127, 48, 127, 54, 121, 51, WHITE);
   }
   else if (i == 27 && mode == 4) {
     display.fillTriangle(127, 48, 127, 54, 121, 51, WHITE);
   }

   //draw envelope param
   display.setTextSize(1);
   display.setCursor(100, 0);//effect param3
   display.print("ATK");
   display.setCursor(100, 16);//effect param3
   display.print("DCY");
   display.setCursor(100, 32);//effect param3
   display.print("ATK");
   display.setCursor(100, 48);//effect param3
   display.print("DCY");
   display.fillRoundRect(100, 9, atk1 + 1, 4, 1, WHITE);
   display.fillRoundRect(100, 25, dcy1 + 1, 4, 1, WHITE);
   display.fillRoundRect(100, 41, atk2 + 1, 4, 1, WHITE);
   display.fillRoundRect(100, 57, dcy2 + 1, 4, 1, WHITE);
 }

 //draw config setting
 if (i >= 28) {  //draw sync mode setting
   display.setTextSize(1);
   display.setCursor(10, 0);
   display.print("SYNC CH1:");
   display.setCursor(72, 0);
   if (sync1 == 0) {
     display.print("TRIG");
   }
   else if (sync1 == 1) {
     display.print("NOTE");
   }
   display.setCursor(10, 9);
   display.print("     CH2:");
   display.setCursor(72, 9);
   if (sync2 == 0) {
     display.print("TRIG");
   }
   else if (sync2 == 1) {
     display.print("NOTE");
   }

   display.setCursor(10, 18);    //draw octave shift
   display.print("OCT  CH1:");
   display.setCursor(10, 27);
   display.print("     CH2:");
   display.setCursor(72, 18);
   display.print(oct1 - 2);
   display.setCursor(72, 27);
   display.print(oct2 - 2);

   display.setCursor(10, 36);    //draw sensitivity
   display.print("SENS CH1:");
   display.setCursor(10, 45);
   display.print("     CH2:");
   display.setCursor(72, 36);
   display.print(sensitivity_ch1 - 4);
   display.setCursor(72, 45);
   display.print(sensitivity_ch2 - 4);

   display.setCursor(10, 54);//draw save
   display.print("SAVE");

   display.drawTriangle(0, 0 + (i - 28) * 9, 0, 6 + (i - 28) * 9, 7, 3 + (i - 28) * 9, WHITE);
 }
 display.display();
}

//-----------------------------OUTPUT----------------------------------------
void intDAC(int intDAC_OUT) {
 analogWrite(A0, intDAC_OUT / 4); // "/4" -> 12bit to 10bit
}

void MCP(int MCP_OUT) {
 Wire.beginTransmission(0x60);
 Wire.write((MCP_OUT >> 8) & 0x0F);
 Wire.write(MCP_OUT);
 Wire.endTransmission();
}

void PWM1(int duty1) {
 pwm(ENV_OUT_PIN_1, 46000, duty1);
}
void PWM2(int duty2) {
 pwm(ENV_OUT_PIN_2, 46000,  duty2);
}

//-----------------------------store data----------------------------------------
void save() {//save setting data to flash memory
 delay(100);
 for ( int j = 0; j <= 7 ; j++ ) {//Convert note setting to bits
   bitWrite(note_str1, j, note1[j]);
   bitWrite(note_str2, j, note2[j]);
 }
 for ( int j = 0; j <= 3 ; j++ ) {
   bitWrite(note_str11, j, note1[j + 8]);
   bitWrite(note_str22, j, note2[j + 8]);
 }

 EEPROM.write(1, note_str1);//ch1 select note
 EEPROM.write(2, note_str11);//ch1 select note
 EEPROM.write(3, note_str2);//ch2 select note
 EEPROM.write(4, note_str22);//ch2 select note
 EEPROM.write(5, atk1);
 EEPROM.write(6, dcy1);
 EEPROM.write(7, atk2);
 EEPROM.write(8, dcy2);
 EEPROM.write(9, sync1);
 EEPROM.write(10, sync2);
 EEPROM.write(11, oct1);
 EEPROM.write(12, oct2);
 EEPROM.write(13, sensitivity_ch1);
 EEPROM.write(14, sensitivity_ch2);
 EEPROM.commit();
 display.clearDisplay();  // clear display
 display.setTextSize(1);
 display.setTextColor(BLACK, WHITE);
 display.setCursor(10, 54);
 display.print("SAVEED");
 display.display();
 delay(1000);
}

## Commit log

2022-02-04 upload new bom and design files for main pcb
    [BOM.csv, main_pcb.kicad_pcb]
2023-03-10 added panel pcb that was missing for whatever reason
2023-07-04 fixed orientation for mcp6002
    [main_pcb.kicad_pcb]
